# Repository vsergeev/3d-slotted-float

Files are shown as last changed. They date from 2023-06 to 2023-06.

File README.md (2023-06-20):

# Parametric Slotted Float

<table>
<tr>
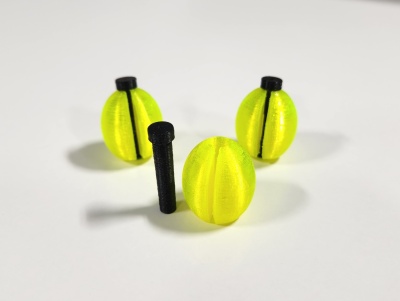
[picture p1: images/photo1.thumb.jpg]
<td></td>
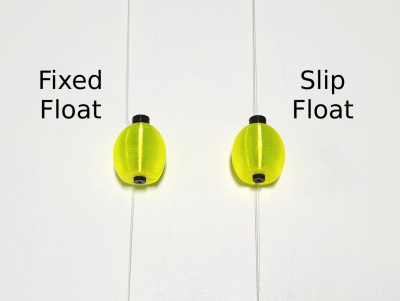
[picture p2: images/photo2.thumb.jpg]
<td></td>
</tr>
<tr>
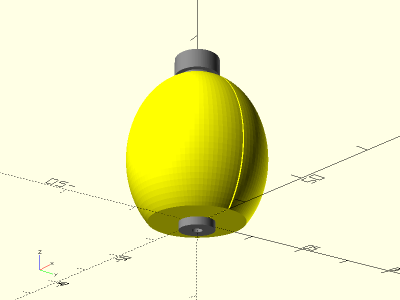
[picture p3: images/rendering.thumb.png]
Rendering 1
<td></td>
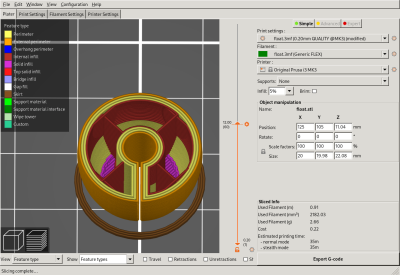
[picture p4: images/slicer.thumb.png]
Slicer
<td></td>
</tr>
<tr>
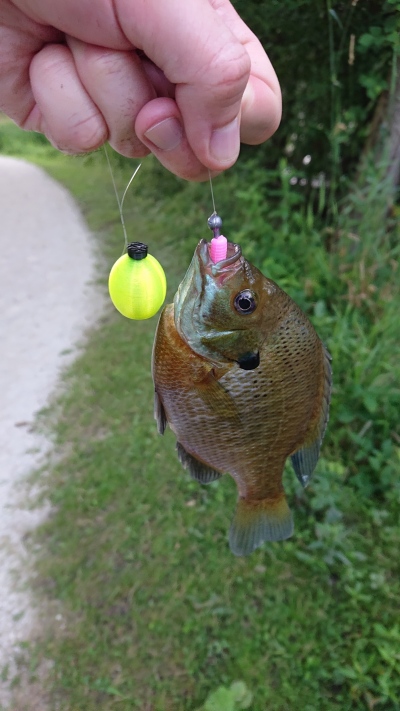
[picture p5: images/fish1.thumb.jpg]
Fish 1
<td></td>
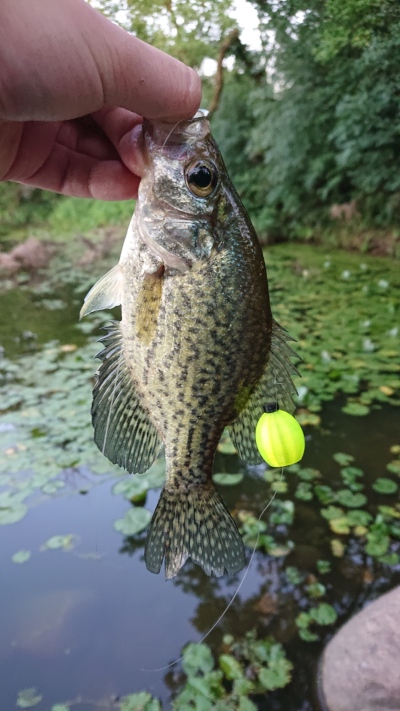
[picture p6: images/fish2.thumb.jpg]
Fish 2
<td></td>
</tr>
<tr>
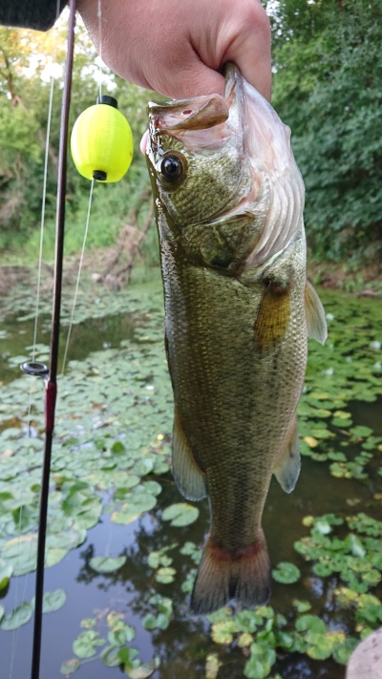
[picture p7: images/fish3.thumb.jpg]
Fish 3
<td></td>
</tr>
</table>

A parametric slotted float that can be used in both fixed and slip float configurations. Float is printed with TPU, using multiple perimeters for water tightness and low infill for buoyancy. Peg is printed with PLA+ or PETG. Made with OpenSCAD.

**Parameters:**

* `float_xy_diameter` - diameter of float, default 20mm
* `float_z_length` - length of float, default 22.5mm
* `float_xy_slot_width` - line slot width, default 0.2mm, can be reduced (e.g. 0.1) for filaments with less expansion
* `float_peg_xy_clearance` - clearance in peg bore, default 0mm, can be increased (e.g 0.25) for less flexible filaments
* `peg_xy_diameter` - diameter of peg, default 5mm
* `peg_z_base_height` - height of peg base, default 3mm

**Design:** [slotted_float.scad](slotted_float.scad)

**STLs:**

* [float_20x22.5mm.stl](stl/float_20x22.5mm.stl)
* [peg_22.5mm.stl](stl/peg_22.5mm.stl)

**Recommended Print Settings:**

* Float - Flexible TPU, 0.20mm layer height, 5% rectilinear infill, 4 top and 4 bottom horizontal layers, 3 perimeters, no supports (see slicer image above for internal visualization)
* Peg - PLA+ or PETG, 0.20mm layer height, 100% infill, no supports

**Filaments Used:**

* TPU - [YOYI 95A TPU Yellow](https://www.amazon.com/gp/product/B07F1T4Q8F/)
* PLA+ - [eSUN PLA+ Black](https://www.amazon.com/eSUN-1-75mm-Printer-Filament-2-2lbs/dp/B01EKEMDA6/)

**Thingiverse:** https://www.thingiverse.com/thing:6085474

**License**:

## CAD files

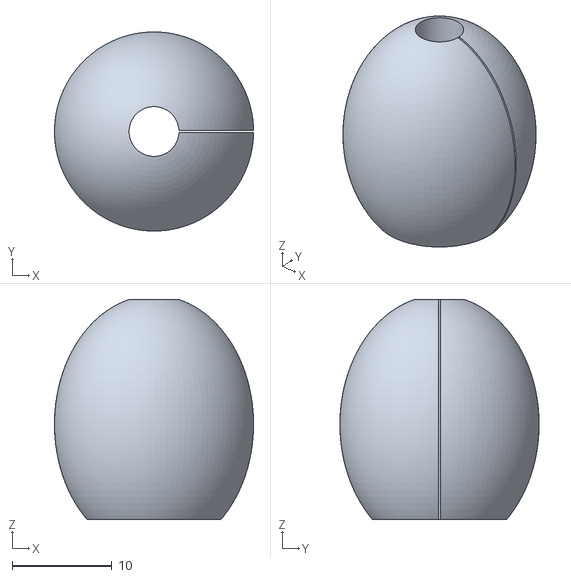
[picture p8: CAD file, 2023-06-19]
stl/float_20x22.5mm.stl
20.0 x 20.0 x 22.1

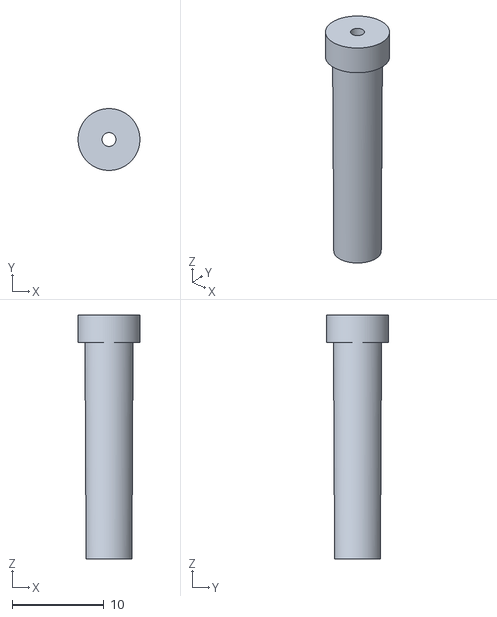
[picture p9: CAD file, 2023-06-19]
stl/peg_22.5mm.stl
6.75 x 6.75 x 26.6

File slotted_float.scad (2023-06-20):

/********************************************************
 * Slotted Float - vsergeev
 * https://github.com/vsergeev/3d-slotted-float
 * CC-BY-4.0
 *
 * Release Notes
 *  * v1.0 - 06/20/2023
 *      * Initial release.
 ********************************************************/

/* [Basic] */

part = "both"; // [both, float, peg]

// in mm
float_xy_diameter = 20;

// in mm
float_z_length = 22.5;

/* [Advanced] */

// in mm, can be reduced to 0.1 for filaments with less expansion
float_xy_slot_width = 0.2;

// in mm, can be increased to 0.25 for less flexible filaments
float_peg_xy_clearance = 0;

// in mm
peg_xy_diameter = 5;

// in mm
peg_z_base_height = 3;

// in mm
peg_xy_base_lip = 1.5;

// in mm
peg_xy_bore_diameter = 1.5;

// peg length scale factor
peg_z_length_scale = 1.05;

// peg taper scale factor
peg_xy_taper_scale = 1.05;

/* [Hidden] */

$fn = 100;

/******************************************************************************/
/* 3D Extrusions */
/******************************************************************************/

module float() {
    cutoff = 0.15; /* 85% */

    difference() {
        /* Ellipsoid */
        intersection() {
            translate([0, 0, (float_z_length * (1 - cutoff)) / 2])
                scale([1, 1, (float_z_length * (1 + cutoff)) / float_xy_diameter])
                    sphere(d=float_xy_diameter);
            cylinder(h=float_z_length * 2, d=float_xy_diameter * 2);
        }

        /* Bore */
        translate([0, 0, -float_z_length / 4])
            cylinder(h=float_z_length * 2, d=peg_xy_diameter + float_peg_xy_clearance);

        /* Line Slot */
        translate([0, -float_xy_slot_width / 2, -float_z_length / 4])
            cube([float_xy_diameter / 1.5, float_xy_slot_width, float_z_length * 2]);
    }
}

module peg() {
    difference() {
        union() {
            /* Base */
            translate([0, 0, peg_z_length_scale * float_z_length])
                cylinder(h=peg_z_base_height, d=peg_xy_taper_scale * peg_xy_diameter + peg_xy_base_lip);

            /* Tapered Peg */
            cylinder(h=peg_z_length_scale * float_z_length, d1=peg_xy_diameter, d2=peg_xy_taper_scale * peg_xy_diameter);
        }

        /* Bore */
        translate([0, 0, -peg_z_length_scale * float_z_length / 4])
            cylinder(h=peg_z_length_scale * float_z_length * 2, d=peg_xy_bore_diameter);
    }
}

/******************************************************************************/
/* Top-level */
/******************************************************************************/

if (part == "both") {
    color("yellow")
        float();
    translate([0, 0, -(peg_z_length_scale - 1) * float_z_length])
        color("grey")
            peg();
} else if (part == "float") {
    color("yellow")
        float();
} else if (part == "peg") {
    color("grey")
        peg();
}

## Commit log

2023-06-19 refactor and improve variable names
    [slotted_float.scad]
2023-06-19 update fragments number from 70 to 100
    [float_20x22.5mm.stl, peg_22.5mm.stl, slotted_float.scad]
2023-06-19 add links to filaments used in readme
2023-06-20 update changelog with v1.0
    [slotted_float.scad]
